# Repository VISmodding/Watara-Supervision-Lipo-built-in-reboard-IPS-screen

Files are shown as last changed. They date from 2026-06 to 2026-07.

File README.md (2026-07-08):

# VIS Watara Supervion PCBs
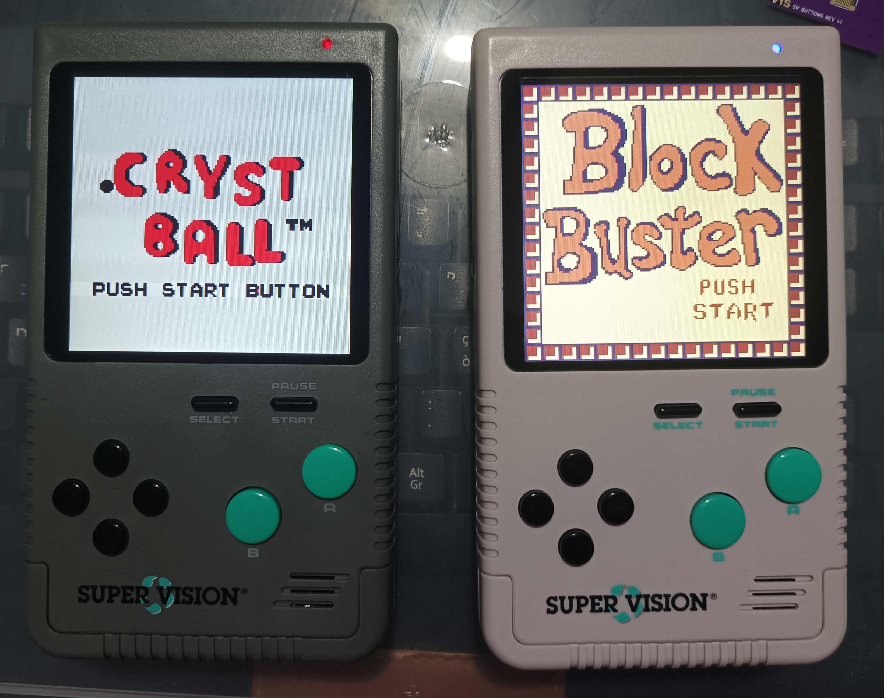
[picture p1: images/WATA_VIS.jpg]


This project (a complete reboard of the Watara Supervision) had been on my mind for a very long time. However, between other commitments and the lack of a proper modern IPS display solution, I kept postponing it.

Everything changed when [DutchMaker](https://github.com/DutchMaker/Supervision-LCD-v2) released an open-source firmware based on the Raspberry Pi Pico platform. Thanks to its straightforward hardware implementation, I immediately realized it was finally time to take the Watara Supervision out of the drawer and start working on a proper modern redesign.

Thanks to this release, it is now possible to retain only the original CPU and cartridge slot from the Watara Supervision while completely rebuilding the rest of the hardware around modern components. The new design features a high-quality IPS display, a LiPo battery powered charge-and-play system, and a fully redesigned PCB with a much cleaner and more professional layout. Circuits are now properly separated, routing has been greatly improved, and the entire architecture is far cleaner and more reliable compared to the original hardware.

The result is a complete modernization of the console that finally overcomes the limitations of the original design — hardware that was clearly engineered with aggressive cost-cutting in mind.

Because the original CPU is packaged as a chip-on-board epoxy blob, it cannot realistically be desoldered or replaced.
Instead of emulating or redesigning the core logic, I opted for a far less common approach: preserving and transplanting the original CPU PCB section directly onto a completely redesigned motherboard.
Solutions like this are rarely seen in the retro modding scene due to the complexity involved in integrating old and new hardware this cleanly.

For this reason, I would not recommend this project to beginners or anyone with limited soldering and hardware modding experience, as the procedure requires a high level of precision and can easily damage the original hardware if performed incorrectly.

## Disclaimer

**This is a DIY project for electronic enthusiasts. For this reason, I am not responsible for any damage incurred while attempting this project or after completion of the project. You alone accept all risk since you are 100% liable for damage to yourself or your property.**

## Security information for Lipo Battery
The battery is physically distant form the MCP73833T-AMI/UN charger. In addition, the following features are implemented:
- Overcharge and overdischarge protections achieved through the widely used and widespread combo FS8205A - DW01A.
- Load sharing: you can safely play while charging the battery since the battery is disconnected from the load while charging (I use the same circuit of SYF Game Gear since its creator allowed me to use it).
  
## Required Donor parts

In this project, the **strictly required donor parts** are only 
  - the **CPU**.
  - the **Cartdrigde slot**.

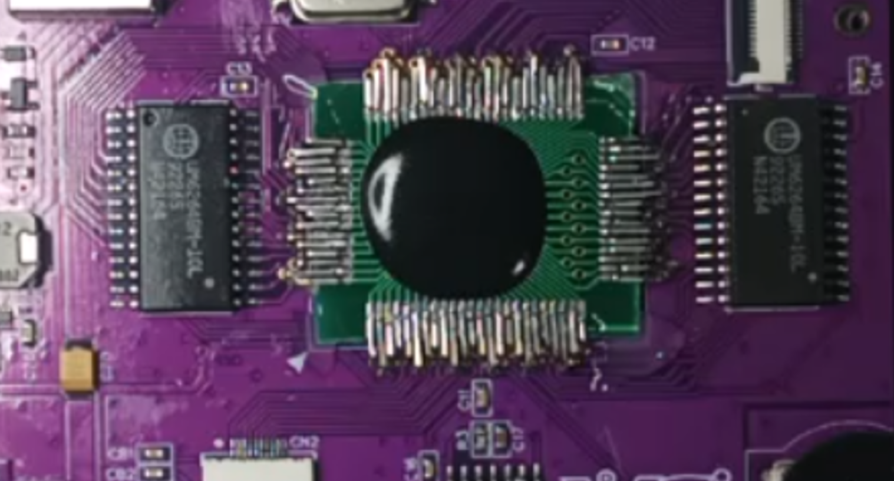
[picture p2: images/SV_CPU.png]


## Components list 

[List here](/Components_list/).

## LCD Firmware Features

Compared to the original firmware released by DutchMaker, several new display-related features have been added.
A dedicated on-screen menu is now available by holding the center button, allowing the user to select different display palettes directly from the console.
Outside of the menu, the UP and DOWN buttons can be used to adjust the display backlight brightness on the fly.
Additionally, pressing the center button twice quickly while outside the menu will save both the currently selected palette and the active backlight level into persistent memory.
This save operation is currently the only feature that may occasionally cause instability, as it can interfere with the video capture process and temporarily freeze the display. If this happens, the console simply needs to be power-cycled, while the save operation itself will still complete successfully.

## LCD Firmware FIX July 2026
Updated the ST7796S LCD initialization sequence using the official EastRising ER-TFT3.92-1 reference code. This fixes the visible horizontal crosstalk/banding on light backgrounds while keeping the original firmware colors, menu and rendering behavior unchanged (in the video this thing can be seen). Now the driver is totally perfect with all background colors!

## LED Indicators

The low level battery indicator LED and the charging indicator LED must be soldered under the power LED. I used 2 blue LEDs so with the console ON I get a purple light (blue+red) while charging or if battery is low (under 3.6v). Clearly you will get a blue light while charging with the console OFF. Referr to the following image for a proper installation (the image was taken from another project but essentially it is the same thing).

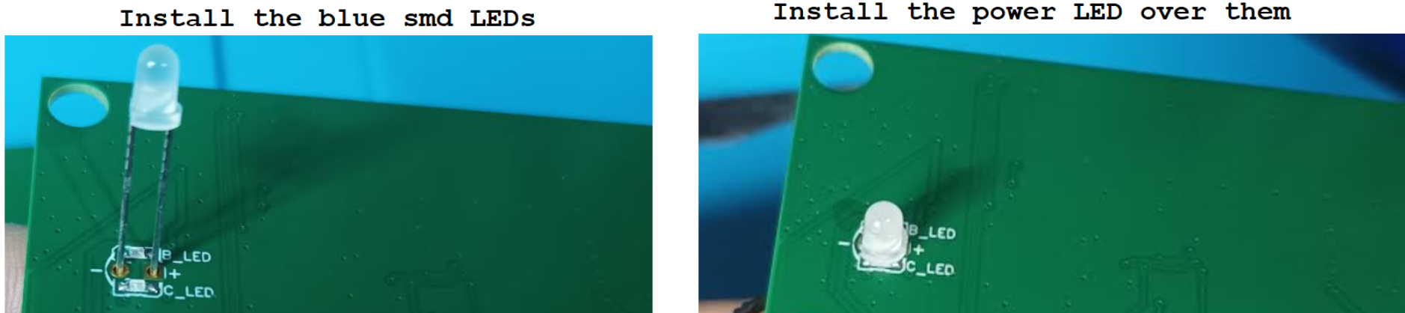
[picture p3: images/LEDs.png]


## Production

In the main folder you find the files for the 3D printed parts and the Gerber files for the audio board and the wheele board (both must be produced with 0.8 mm thickness).
The other boards must be produced on PCBWay at the following links:

<a href="https://www.pcbway.com/project/shareproject/Watara_Supervision_MAINBOARD_VIS_Version_ecdf735c.html">PCB from PCBWay</a>
<a href="https://www.pcbway.com/project/shareproject/Watara_Supervision_IPS_BOARD_BUTTONS_BOARD_VIS_Version_4c34237c.html">PCB from PCBWay</a>

## YouTube Video for the setup

[Link_here](https://youtu.be/5hr6UCZzYD0?si=VRYktYd-8LlZ20KM)

## Minimal Instructions to program the Pico Ic
  -  Compile the firmware source files to obtain the UF2 file (follows the [DutchMaker](https://github.com/DutchMaker/Supervision-LCD-v2) repository and ask some help to AI tools).
  -  Populate the IPS PCB.
  -  Without anything connected to the IPS PCB, put the SW2 switch in POS B and keep pressed the SW1 switch while connecting (with an USB cable) the IPS board to a computer. Once connected, a virtual drive will appear on your computer (you can now stop keep pressing SW1). Simply copy the UF2 file onto the drive (at this point the drive will be disconnected from the computer). Disconnect also the USB cable from the IPS board.
  -  Finally, put the SW2 switch in POS A and connect the LCD to the VIS mainboard to test your soldering job.
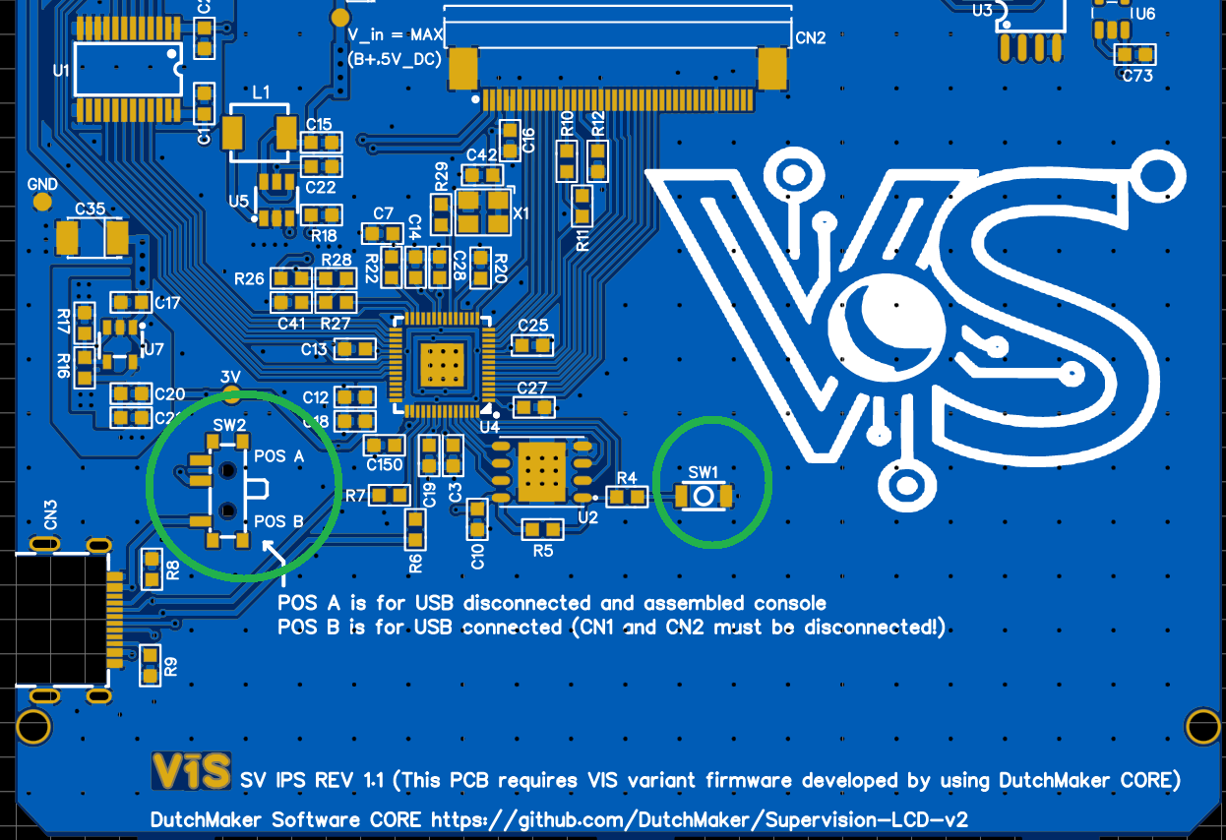
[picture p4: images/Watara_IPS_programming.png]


## Power Consumption 
I have done some fast measurements. Maybe I will carefully update in the future these numbers.

| Setup / Operating State | Input Voltage | Measured Current Draw (Amperometer) | Notes & Component Behavior |
| :--- | :--- | :--- | :--- |
| **Full Load (Max Brightness & Audio)** | 5V DC | ~300 mA (0.3A) | IPS Display at max duty cycle, audio volume at maximum. |
| **Standard Play (Low/Mid Brightness)** | 5V DC | ~170 mA (0.17A) | Optimized brightness levels for battery saving. |
| **Stock Logic Only** | 5V DC | ~55 - 56 mA | Baseline consumption of the CPU/Logic, excluding screen and audio amplification. |

## Credits

- [DutchMaker](https://github.com/DutchMaker/Supervision-LCD-v2) for creating the open-source firmware used to drive the IPS LCD on the Watara Supervision.

- [Tobi](https://www.embedded-ideas.de/posts/250417_open_dmg_display/) (creator of the Open DMG Display / ODD project) for all the support provided during the development of this project, especially regarding LCD backlight management.

- [Modding Marius](https://moddingmarius.com/) for the continuous support and for helping me source an excellent power switch that was used in this project and will likely be useful for future projects as well.

- [Bucket Mouse](https://github.com/MouseBiteLabs/) for the [DMGC](https://github.com/MouseBiteLabs/Game-Boy-DMG-Color) project, from which I took inspiration and reused several ideas throughout this build.

- [consolesandcasks / Deceptive Thinker](https://github.com/consolesandcasks) for the [Heavy CPU MGB](https://github.com/ConsolesandCasks/CPU-MGB-Heavy) project, which I referenced while redesigning and upgrading the DC jack section. He also provided many useful suggestions for the low level battery indicator.

- [Mathijs](https://syf.nl/) from SYF Game Gear for the many suggestions, ideas, and circuits shared with me over the years.

- [Kevtris](http://blog.kevtris.org/blogfiles/Supervision_Tech.txt) for the Supervision reverse engineering notes, which were extremely useful during the development process.

## License
<br />This work is licensed under a <a rel="license" href="http://creativecommons.org/licenses/by-sa/4.0/">Creative Commons Attribution-ShareAlike 4.0 International License</a>. You are able to copy and redistribute the material in any medium or format, as well as remix, transform, or build upon the material for any purpose (even commercial) - but you **must** give appropriate credit, provide a link to the license, and indicate if any changes were made.
The firmware follows the DutchMaker [NON-COMMERCIAL USE LICENSE](https://github.com/DutchMaker/Supervision-LCD-v2/blob/main/LICENSE) since here it is  published just a variant.

## Contacts

**email**: vis.modding@gmail.com <br />

**discord**: you can find me as *vis_modding* on several servers (BennVenn, Mouse Bit Lab, Retrosix modding, Game Boy, Gameboy makers, Cybdyn Systems, Pixel FX Official Discord, Modded Gameboy Club).

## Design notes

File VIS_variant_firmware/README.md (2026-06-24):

[⬅️ Back to Main](../README.md)

## 🛠️ DutchMaker VIS Variant Firmware

This firmware is a customized version of the **[Original DutchMaker Project](https://github.com/DutchMaker/Supervision-LCD-v2)**. 

> [!IMPORTANT]
> **A huge thank you to DutchMaker** for his incredible work and for sharing the original source code with the community. Without his foundation, this "Total Reboard" project wouldn't have been possible.

This specific fork has been adapted for the **VIS hardware variant**, introducing key improvements to the core synchronization logic and a new physical user interface.

> [!NOTE]
> **Disclaimer:** As I am not an expert in firmware development, I utilized AI tools (Gemini and ChatGPT) to assist in writing the code, debugging synchronization issues, and drafting this documentation. This project is the result of a collaborative effort between human hardware design and AI-assisted software development.

### ⚡ Critical Fixes & Improvements
* **Multi-Core Sync Fix (Volatile Qualifier):** In the original implementation, the `sync` flag (shared between Core 0 for capture and Core 1 for rendering) lacked the `volatile` qualifier. This caused the compiler to cache the variable in registers, preventing the render core from seeing updates from the capture core. 
    * **Result:** Fixed the "stuck on splash screen" issue, ensuring reliable cross-core communication.
* **Render Startup Optimization:** Improved the `render_core()` initialization by forcing `sync = 1` after the first frame. This ensures the render loop activates immediately and stays perfectly in phase with the capture hardware.
* **Physical UI (Thumbwheel):** Added support for a 3-way navigation switch (Up/Down/Click) to manage:
    * **Brightness:** Real-time PWM backlight control.
    * **Palette Switching:** On-screen menu to toggle between color profiles.

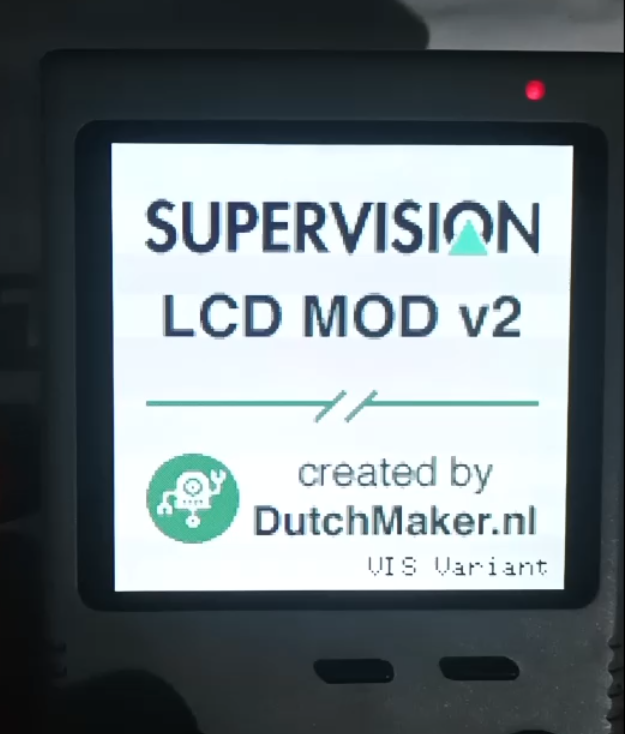
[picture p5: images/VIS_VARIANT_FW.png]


### 📜 License & Building
This project follows the **same license** as the original DutchMaker repository. 

To respect the original author's work and ensure hardware compatibility, **pre-compiled binaries (.uf2) are not provided.** You must compile the firmware yourself:

1. Setup the **Raspberry Pi Pico SDK**.
2. Clone this repository.
3. Follow the standard `cmake` and `make` workflow.

> [!IMPORTANT]
> For detailed build instructions, please refer to the [Original DutchMaker Documentation](https://github.com/DutchMaker/Supervision-LCD-v2).

---

### 📺 LCD Interface (8-Bit Parallel)
Sice the data pins are mapped in reverse order (**D0 → GPIO7** through **D7 → GPIO0**) to simplify PCB routing, the firmware includes a fast bit-reversal function. If you are using this firmware on different hardware, you may need to adjust the `reverse_bits()` function in `lcd.c`.

| Signal | Pin (GPIO) | Notes |
| :--- | :---: | :--- |
| **LCD_D0** | 7 | Inverted Mapping |
| **LCD_D1** | 6 | |
| **LCD_D2** | 5 | |
| **LCD_D3** | 4 | |
| **LCD_D4** | 3 | |
| **LCD_D5** | 2 | |
| **LCD_D6** | 1 | |
| **LCD_D7** | 0 | |
| **LCD_RD** | 8 | Read Signal (Active Low) |
| **LCD_WR** | 9 | Write Signal (Pulse) |
| **LCD_DC** | 10 | Data / Command Select |
| **LCD_CS** | 11 | Chip Select |
| **LCD_RST**| 12 | Hardware Reset |

### 🎮 Console Supervision Signals
Dedicated pins for capturing raw video data and synchronization signals from the original console hardware.

| Signal | Pin (GPIO) | Notes |
| :--- | :---: | :--- |
| **DATA 0** | 22 | |
| **DATA 1** | 21 | |
| **DATA 2** | 20 | |
| **DATA 3** | 19 | |
| **P_CLOCK**| 18 | Pixel Clock |
| **F_POL** | 17 | Frame Polarity |

### 🛠️ User Interface & Control
| Signal | Pin (GPIO) | Notes |
| :--- | :---: | :--- |
| **BACKLIGHT**| 16 | PWM Brightness Control |
| **WHEEL_UP** | 25 | Navigation (Internal Pull-up) |
| **WHEEL_MID**| 24 | Menu Select / Click |
| **WHEEL_DWN**| 23 | Navigation (Internal Pull-up) |

---

### ❄️ System Freeze (The Only Firmware Issue)

Due to the real-time nature of this project, writing settings to the Flash memory can occasionally cause the system to freeze. 

## 🎨 Custom Color Palettes

The firmware includes a wide variety of color profiles to enhance the retro-gaming experience. You can cycle through them using the **3-way thumbwheel** (Click to open menu, Up/Down to toggle).

### Built-in Palettes
The following profiles are already available in `lib/palette.c` but if you want to create your own color scheme, you can modify the `palettes` array in `lib/palette.c` before compiling:

```c
static const pal_t palettes[] = {
    {"Default",        {0xB0CB65, 0x607623, 0x415115, 0x1A2108}},
    {"Monochrome",     {0xD2D2D2, 0xAAAAAA, 0x555555, 0x000000}},
    {"DMG Classic",    {0x9BBC0F, 0x8BAC0F, 0x306230, 0x0F380F}},
    {"DMG Tetris",     {0xFFFFFF, 0xFFFF00, 0xFF0000, 0x000000}},
    {"SNES",           {0xF7E7C6, 0xD68E49, 0xA63725, 0x331E50}},
    {"CGB Default",    {0xFFFFB5, 0x7BFF31, 0x00AD52, 0x000000}},
    {"CGB Blue",       {0xFFFFFF, 0x63A5FF, 0x0000FF, 0x000000}},
    {"CGB Dark Blue",  {0xFFFFFF, 0x8C8CDE, 0x52528C, 0x000000}},
    {"CGB Gray",       {0xFFFFFF, 0xA5A5A5, 0x525252, 0x000000}},
    {"CGB Pastel",     {0xFFFFA5, 0xFF9494, 0x9494FF, 0x000000}},
    {"CGB Orange",     {0xFFFFFF, 0xFFFF00, 0xFF0000, 0x000000}},
    {"CGB Yellow",     {0xFFFFFF, 0xFFFF00, 0x7B4A00, 0x000000}},
    {"CGB Green",      {0xFFFFFF, 0x52FF00, 0xFF4200, 0x000000}},
    {"CGB Dark Green", {0xFFFFFF, 0x7BFF31, 0x0063C5, 0x000000}},
    {"CGB Inverted",   {0x000000, 0x008484, 0xFFDE00, 0xFFFFFF}},
};

```
Each palette is composed of 4 colors in HEX (RGB888) format. The firmware will automatically handle the conversion for the display.
Take a look [here](https://tcrf.net/Notes:Game_Boy_Color_Bootstrap_ROM#Assigned_Palette_Configurations) to see for example the background color of CGB that I have used.

[⬅️ Back to Main](../README.md)

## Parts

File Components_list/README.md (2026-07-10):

[COME BACK TO HOMEPAGE](../README.md)

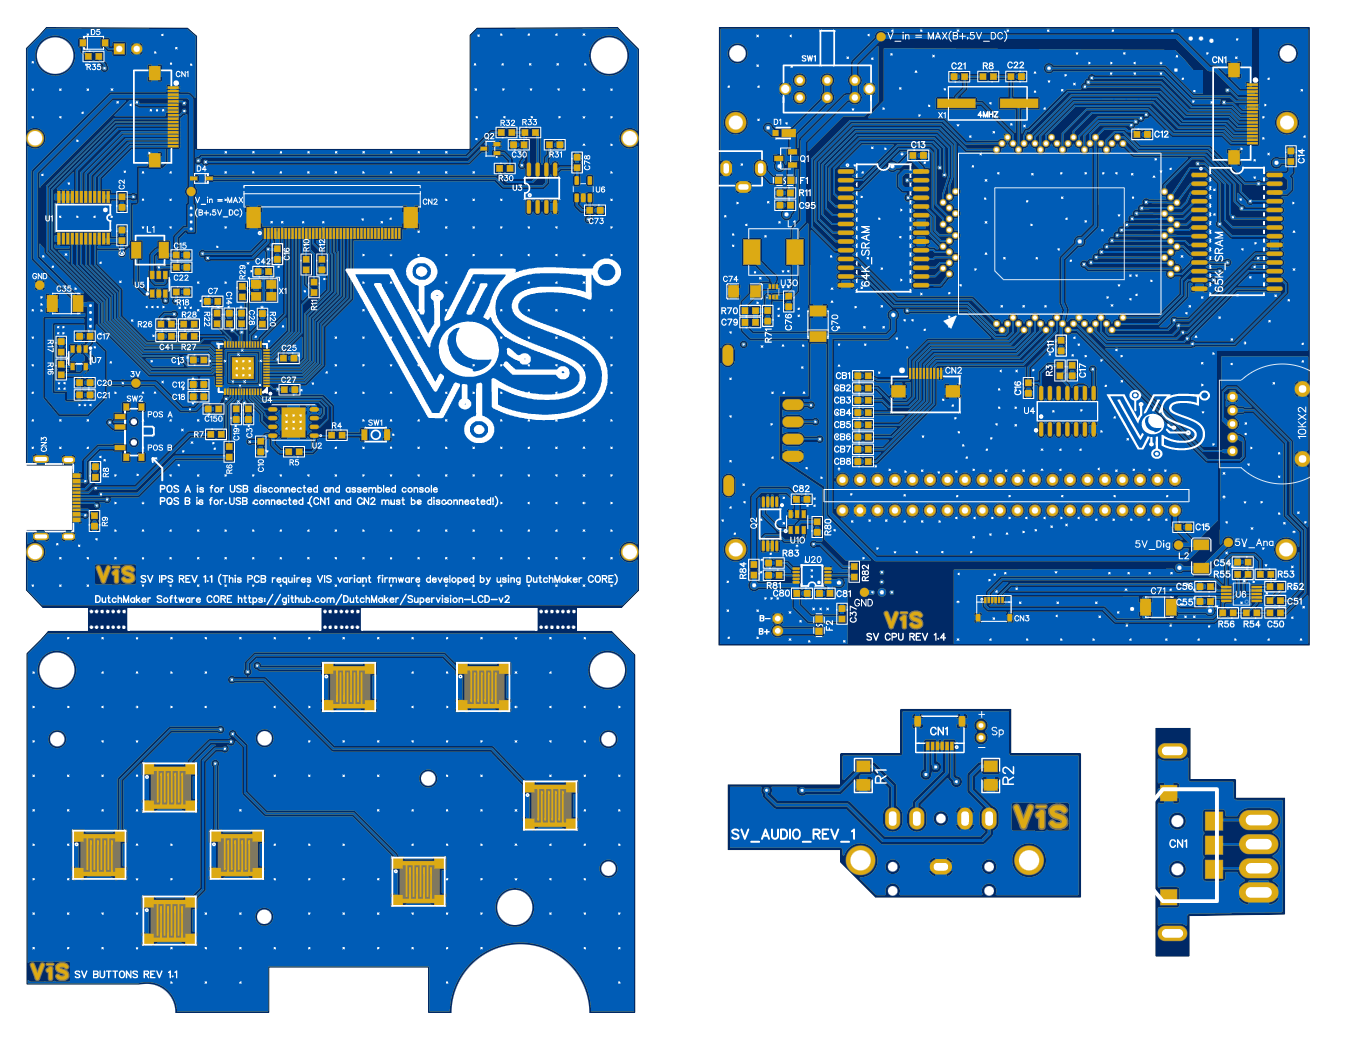
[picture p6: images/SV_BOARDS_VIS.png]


## General components that can be purchased on several shops

- Length 8 CM, 10Pin, Pitch 0.5mm, Reverse Direction FPC/FFC cable
- Length 5 CM, 18Pin, Pitch 0.5mm, Reverse Direction FPC/FFC cable
- Length 10 CM, 6Pin, Pitch 0.5mm, Forward Direction FPC/FFC cable
- 1 or 2 Watt speaker (8 Ω) with jst connector
- ER-TFT3.92-1 Display ([Datasheet](https://www.buydisplay.com/download/manual/ER-TFT3.92-1_Datasheet.pdf)) See more details on the [Original DutchMaker Project](https://github.com/DutchMaker/Supervision-LCD-v2)
- 10 cm x 10 cm x 1mm Transparent Acrylic Sheet (if you plan to make a screen lens alone)
- Single and double rows 1.27 pin headers (to grab the PINs required to solder the SV CPU)
- 3.7V 125054 Lipo battery
- 5v 2A USB-C charger with the 2A cable USB adapter (I suggest the right angle version) that can be purchased here [Link Aliexpress](https://www.aliexpress.com/item/4000285082506.html).
- Brackets (3D printed)

## Bill of Materials (MAINBOARD)
    
| Reference Designators | Description  | Mfr. Part # | LCSC code | 
| --- | --- | --- | --- |
| Power Switch | Slide Switch | EG2210 | C3664585 |
| Slot cardridge and CPU| grab from the SV PCB | - | - |
| Potentiometer B103 10 kΩ 5 pin | [Aliexpress](https://www.aliexpress.com/item/1005007467632806.html)  | - | - |
| DC Jack 3.5 mm x 1.35 mm | 2A 24V | DC-002-2.0A-1.3 | C381119 |
| Quartz Crystal |  Crystal 4MHz | X49SM4MSD2SC | C13774 |
| RAM (SOP-28 SRAM) x 2 | AS6C6264-55SIN or grab from the SV PCB  | AS6C6264-55SIN | C1349771 |
| R3, R52, R54 | 20 kΩ 0603 resistor | RC0603FR-0720KL | C105575 |
| R8 | 1 MΩ 0603 resistor | RC0603FR-071ML | C105578 |
| R11 | 47 kΩ 0603 resistor | RC0603FR-0747KL | C105579 |
| R53, R56 (for 1 or 2 Watt speaker) | 15 kΩ 0603 resistor | RC0603FR-0715KL | C114661 |
| R55, R71 | 100 kΩ 0603 resistor | RC0603FR-07100KL | C14675 |
| R70 | 732 kΩ 0603 resistor | AC0603FR-07732KL | C228042 |
| R80 | 1 kΩ 0603 resistor | RC0603FR-071KL | C22548 |
| R81 | 10 kΩ 0603 resistor | RC0603FR-0710KL | C98220 |
| R82 | 7.5 kΩ 0603 resistor | AF0603FR-077K5L | C144113 |
| R83 (for 0.5A charging) | 3 kΩ 0603 resistor | RC0603FR-073KL | C126358 |
| R83 (for 0.9A charging) | 1.8 kΩ 0603 resistor | RC0603FR-071K8L | C185354 |
| R84 | 100 Ω 0603 resistor | RC0603FR-07100RL | C105588 |
| C11, C12, C13, C14, C15, C16, C82, CB1-CB8 | 100 nF 100 V 0603 capacitor | GCJ188R72A104KA01D | C161117 |
| C17 | 25 V 4.7 μF 0603 capacitor | GRM188R61E475KE11D | C90057 |
| C21, C22 | 22 pF 50 V 0603 C0G capacitor | CC0603JRNPO9BN220 | C105620 |
| C37 | 10 μF 10 V 0603 capacitor | GRM188R61A106KE69D | C77044 |
| C50, C51 | 390 nF 16 V 0603 capacitor | GCM188R71C394KA55D | C437460 |
| C54, C55, C56, C80, C81, C95 | 1 uF 16 V 0603 capacitor | GRM188R71C105KE15D | C77049 |
| C70, C71 | 100 μF 10 V (tantalum) capacitor | T491B107K010AT | C122271 |
| C74 | 100 μF 10V 1206 capacitor | GRM31CR61A107ME05L | C312983 |
| C76 | 22 uF 10V 0603 capacitor| GRM188R61A226ME15D | C84419 |
| C79 | 100 pF 50V 0603 capacitor| CC0603JRNPO9BN101 | C14665 |
| D1 | 30 V 2 A Schottky Diode | PD3S230HQ-7 | C460243 |
| D2 | 100 mA Switching Diode | 1SS355VMTE-17 | C111695 |
| F1, F2 | 6 V 2 A resettable fuse 0603 | BSMD0603L-200 | C2757930 |
| Q1 | 30 V 4.2 A P channel monsfet | AO3401A | C306862 |
| Q2 | 20 V 6 A mosfet | FS8205A | C16052 |
| U10 | SOT23-6 Battery | DW01A | C18164398 |
| U20 | Charger Ic | MCP73833T-AMI/UN | C627668 |
| U30 | boost converter | TPS61023DRLR | C919459 |
| U4 | SN74HC14DR or grab 74HC14 Ic from the SV PCB | SN74HC14DR | C6820 |
| U6 | Audio Amp VSSOP-10 Amps | LM4853MM/NOPB | C2872995 |
| L1 | 6A 2.2uH Power Inductor | MHCI06018-2R2M-R8A | C142092 |
| L2 | 200 mA 5.6 μH 1210 inductor | NLV32T-5R6J-EF | C295106 |
| CN1 | 18 pins connector 0.5 mm pitch  | AFC01-S18FCA-00 | C262666 |
| CN2 | 10 pins connector 0.5 mm pitch | HC-FPC-0.5-10P-FH20 | C19273927 |
| CN3 | 6 pins connector 0.5 mm pitch  | THD0509-06CL-GF | C283134 |
| IPS Wheele | Surface Mount Navigation Switch  | COM-08184 | - |

## Bill of Materials (AUDIOBOARD)
    
| Reference Designators | Description  | Mfr. Part # | LCSC code | 
| --- | --- | --- | --- |
| R1, R2 | 1 kΩ 125mW 0805  | RC0805FR-071KL | C95781 |
| C1, C2, C3 | 100 μF 6.3V tantallum capacitor  | 6TPE100MAZB | C79109 |
| CN4 | 6 pins connector 0.5 mm pitch  | THD0509-06CL-GF | C283134 |
| CN5 | Audio Jack | PJ-307 | C22355760 |
| CN6 | 2 pins connector for speaker  | 1.25-2AW | C722595 |

## Bill of Materials (IPS BOARD)

| Reference Designators | Description  | Mfr. Part # | LCSC code | 
| --- | --- | --- | --- |
| R4, R26, R29, R30 | 1 kΩ 0603 resistor | RT0603FRE131KL | C5220830 |
| R5, R10, R11, R12, R20, R22 | 10 kΩ 0603 resistor | RC0603FR-0710KL | C98220 |
| R6, R7 | 27 Ω 0603 resistor | RC0603FR-0727RL | C137753 |
| R8, R9, R27, R28 | 5.1 kΩ 0603 resistor | RC0603FR-075K1L | C105580 |
| R16 | 47 kΩ 0603 resistor | RC0603FR-0747KL | C105579 |
| R17 | 33 kΩ 0603 resistor | RC0603FR-0733KL | C126359 |
| R18 | 5.1 Ω 0603 resistor | AC0603FR-075R1L | C227988 |
| R31 | 1.5 MΩ 0603 resistor | RC0603FR-071M5L | C137773 |
| R32 | 7.5 kΩ 0603 resistor | AF0603FR-077K5L | C144113 |
| R33 | 4.7 kΩ 0603 resistor | RC0603FR-074K7L | C99782 |
| R35 | 2 kΩ 0603 resistor |  AC0603DR-072KL | C227483 |
| C1, C2, C3, C7, C10, C12, C13, C14, C18, C19, C21, C25, C27, C28, C41, C42 | 100 V 100 nF 0603 capacitor | GCJ188R72A104KA01D | C161117 |
| C30 | 25 V 4.7 μF 0603 capacitor | GRM188R61E475KE11D | C90057 |
| C15, C150, C73, C78 | 16 V 1 μF 0603 capacitor | GRM188R71C105KE15D | C77049 |
| C16, C17, C20 | 10 V 10 μF 0603 capacitor | GRM188R61A106KE69D | C77044 |
| C22 | 10 V 220 nF 0603 capacitor | GCM188R71H224KA64D | C97857 |
| C35 | 6.3 V 220 μF tantalum capacitor | 6TPE220MAZB | C79111 |
| CN1 | 18 pins connector 0.5 mm pitch  | AFC01-S18FCA-00 | C262666 |
| CN2 | 40 pins connector 0.5 mm pitch | 05A20L40P | C5362161 |
| CN3 | USB-C connector  | TPS16-N1F1-2016-A | C22357897 |
| D4 | 100 mA switching diode  | 1SS355VMTE-17 | C111695 |
| D5 | Zener diode  | MMSZ5227BT1G | C154803 |
| Q2 | 45V 100mA Bipolar (BJT)  | BC847W | C2910228 |
| L1 | 1.2 A 22 μH Inductor  | APH0420T220M | C5349666 |
| U1 | Logic converter | SN74LVC8T245PWR | C27643 |
| U2 | 16 Mbit  memory | W25Q16JVZPIQ | C377853 |
| U3 | 2mV 25nA SOIC-8Comparator | LM393DR | C67470 |
| U4 | RP2040 | RP2040 or SC0914(13) | C3227924 or C2040 |
| U5 | Boost converter | AP3019AKTR-G1 | C44956 |
| U6 | 3.3v LD0 SOT23-5 | NCP161ASN330T1G or TPNCP161ASN330T1G | C892187 or C3021095|
| U7 | LDO | SPX3819M5-L/TR | C9056 |
| X1 |  Crystal | OT2EL89CJI-111YLC-12M | C5280582 |
| POWER LED RED | 3 mm red LED (cloudy lens) | MHL3014SRTS | C397053 |
| B_LED, C_LED | 0603 blue LED | 19-217/BHC-ZL1M2RY/6T | C2986058 |
| SW1 | 3x2 mm tactile switch | 1TS015A-2000-0600-CT | C256106 |
| SW2 |  switch | SSSS811101 | C109335 |

## Bill of Materials (BUTTONS BOARD)

| Reference Designators | Description  | Mfr. Part # | LCSC code | 
| --- | --- | --- | --- |
| Tactile switch (D-PAD. A, B, Start/select) x 8 |  7 mm 0.6 mm Round Button | SKRRABE010 or SKRRAAE010 | C125046 or C97437|
| CN4 | 10 pins connector 0.5 mm pitch | HC-FPC-0.5-10P-FH20 | C19273927 |

[COME BACK TO HOMEPAGE](../README.md)

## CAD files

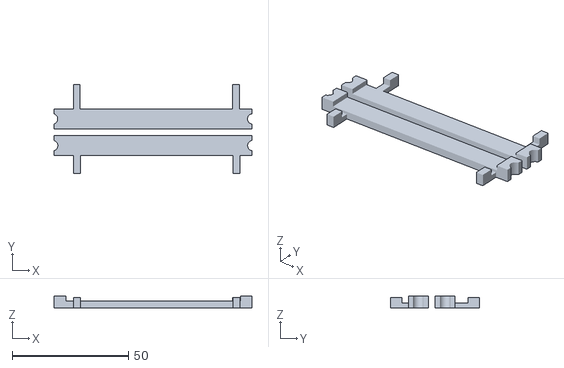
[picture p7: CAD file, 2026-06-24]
SV_LCD_BBRACKET_VIS.stl
85.2 x 38.4 x 5.00

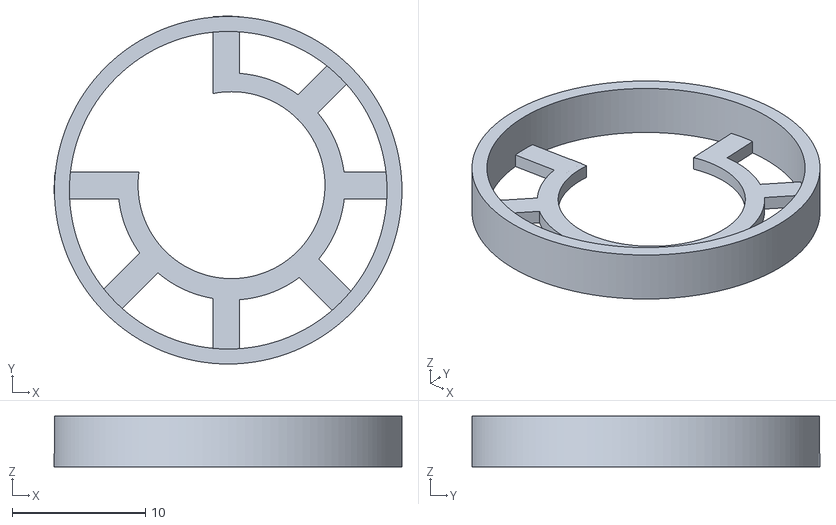
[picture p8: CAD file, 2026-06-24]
SV_23mm_SPEAKER_HOLDER_VIS.stl
26.1 x 26.1 x 3.80

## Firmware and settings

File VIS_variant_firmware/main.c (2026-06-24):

#include <pico/multicore.h>
#include <pico/stdlib.h>
#include <stdio.h>
#include <hardware/vreg.h>
#include <hardware/clocks.h>
#include "lib/supervision.h"
#include "lib/lcd.h"
#include "lib/menu.h"
#include "lib/palette.h"
#include "lib/settings.h"
#include "lib/brightness.h"

volatile uint8_t sync = 0;
volatile uint8_t render_buffer_index = 0;
volatile bool game_active = false;

// --- CORE 1: Rendering e Menu ---
void __time_critical_func(render_core)() {
    lcd_init();
    settings_init();
    brightness_init();

    palette_apply_splash();
    inject_vis_variant_overlay(1);
    
    lcd_render_framebuffer(render_buffer_index);

    menu_init();
    bool palette_loaded = false;

    sync = 1;

    while (true) {
        
        if (game_active && !palette_loaded) {
            palette_init(); 
            palette_loaded = true;
        }

        menu_update();

        if (sync) {
            if (menu_is_visible()) {
                menu_draw_overlay(render_buffer_index);
            }
            lcd_render_framebuffer(render_buffer_index);
        }
    }
}

// --- CORE 0: Capture Data (Bus Supervision) ---
void __not_in_flash_func(capture_data)() {
    uint8_t last_clock_state = 0;
    uint8_t last_polarity_state = 1;
    uint8_t field = 0;
    
    uint8_t *buffer = get_framebuffer(1);
    
    supervision_gpio_init();

    // Wait a new frame from the console
    while (gpio_get(SV_PIN_FRAME_POLARITY)) {}
    while (!gpio_get(SV_PIN_FRAME_POLARITY)) {}

    while (true) {
        const uint32_t bus = gpio_get_all();
        const uint8_t clock = (bus >> SV_PIN_PIXEL_CLOCK) & 1;
        const uint8_t polarity = (bus >> SV_PIN_FRAME_POLARITY) & 1;

        if (clock && !last_clock_state) {
            
            if (!game_active) {
                game_active = true;
            }

            if (field == 0) {
                *buffer++ = (bus >> SV_PIN_DATA0) & 1;
                *buffer++ = (bus >> SV_PIN_DATA1) & 1;
                *buffer++ = (bus >> SV_PIN_DATA2) & 1;
                *buffer++ = (bus >> SV_PIN_DATA3) & 1;
            } else {
                *buffer++ += (bus >> SV_PIN_DATA0) & 1;
                *buffer++ += (bus >> SV_PIN_DATA1) & 1;
                *buffer++ += (bus >> SV_PIN_DATA2) & 1;
                *buffer++ += (bus >> SV_PIN_DATA3) & 1;
            }
        }

        if (polarity != last_polarity_state) {
            if (field == 2) {
                if (!sync) {
                    render_buffer_index = !render_buffer_index;
                    sync = 1;
                }
                field = 0;
            } else {
                field++;
            }
            buffer = get_framebuffer(!render_buffer_index);
        }

        last_clock_state = clock;
        last_polarity_state = polarity;
    }
}

int main() {
    // Overclock to 240 MHz for fast bit-banging 
    vreg_set_voltage(VREG_VOLTAGE_1_20);
    sleep_ms(10);
    set_sys_clock_khz(240000, true);
    sleep_ms(10);

    sleep_ms(50);
    multicore_launch_core1(render_core);

    sleep_ms(1000);
    capture_data();
    
    return 0;
}
